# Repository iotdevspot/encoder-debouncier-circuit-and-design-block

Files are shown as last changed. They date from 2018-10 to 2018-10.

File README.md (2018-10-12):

# encoder-debouncier-circuit-and-design-block

I've tried to use an encoder in one of my previous projects and it was quite hard to use due to the bouncing. Here is two version of encoder debouncer circuits (as an Eagle Design Blocks .dbl) with links where I found them and I've created some modules to test them (.brd, and .sch files). The second version had been implemented and it worked fine for me. I've managed to create a quite cool UI with it. Every component has 3D model, so I've synced it with Fusion360 too. Here is how it's look: 

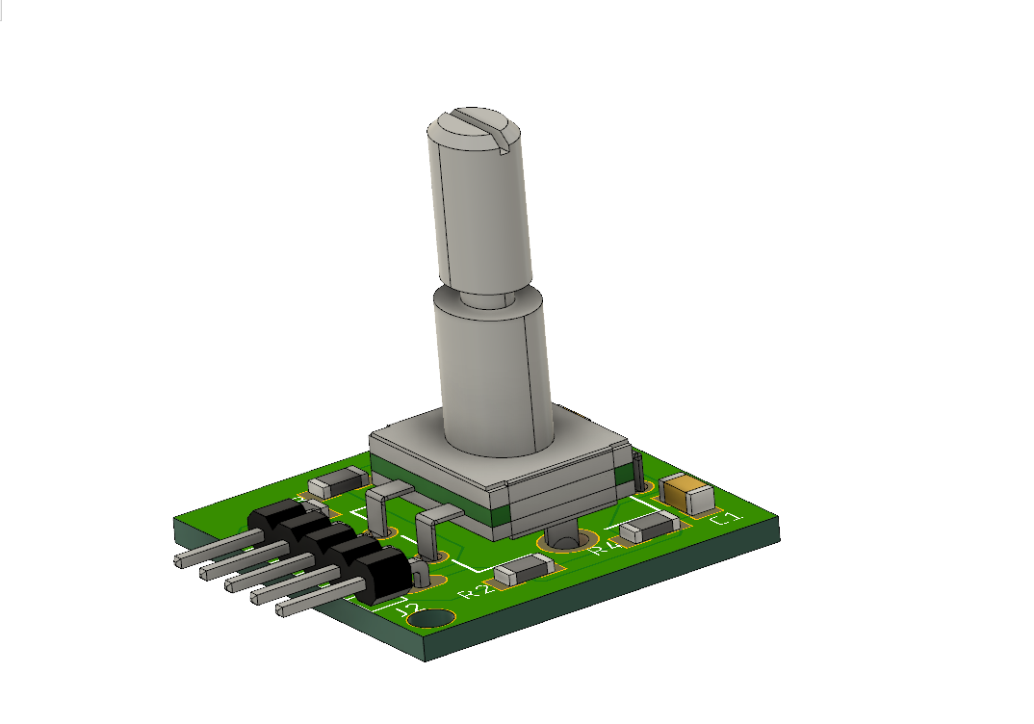
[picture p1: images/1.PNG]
image of Fusion360


*[ROBERT DEE](https://grabcad.com/library/rotary-encoder-6)s encoder model had been used from GrabCAD*

**How to connect (module to board):**
- 5V - supply voltage
- GND - ground
- SW - button input, digital in
- DT - B channel of encoder
- CLK - A channel of encoder

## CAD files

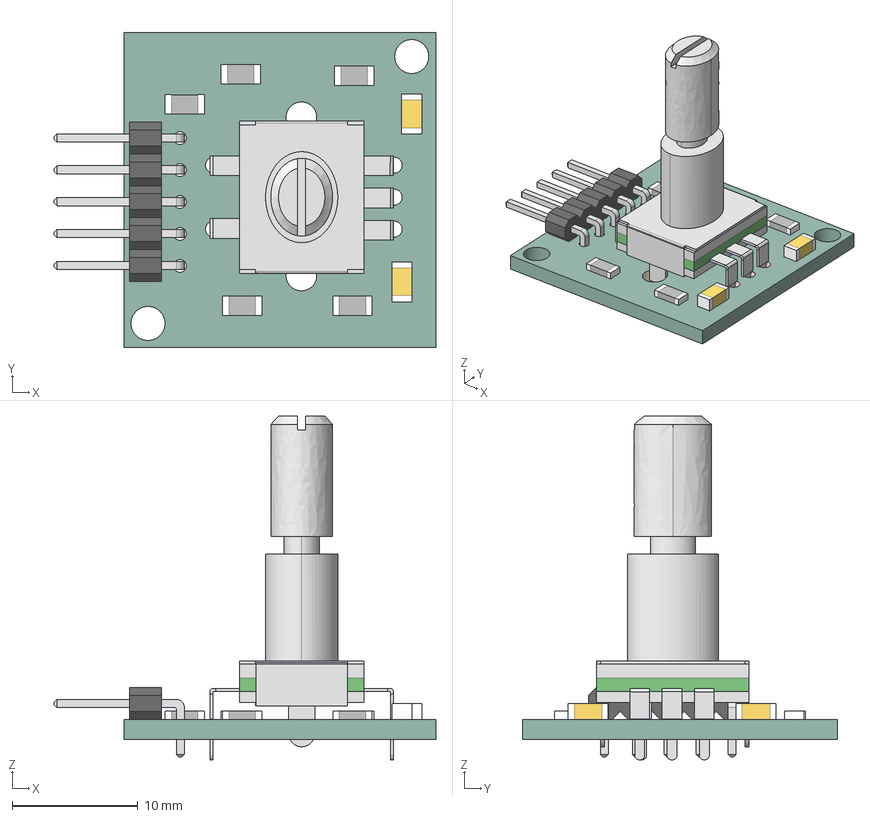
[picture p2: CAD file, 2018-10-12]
type1/smd/encoder-switch-type1-smd v3.step
30.4 x 25.0 x 27.3 mm
Board
10nF x 2
1X05/90
82K x 5

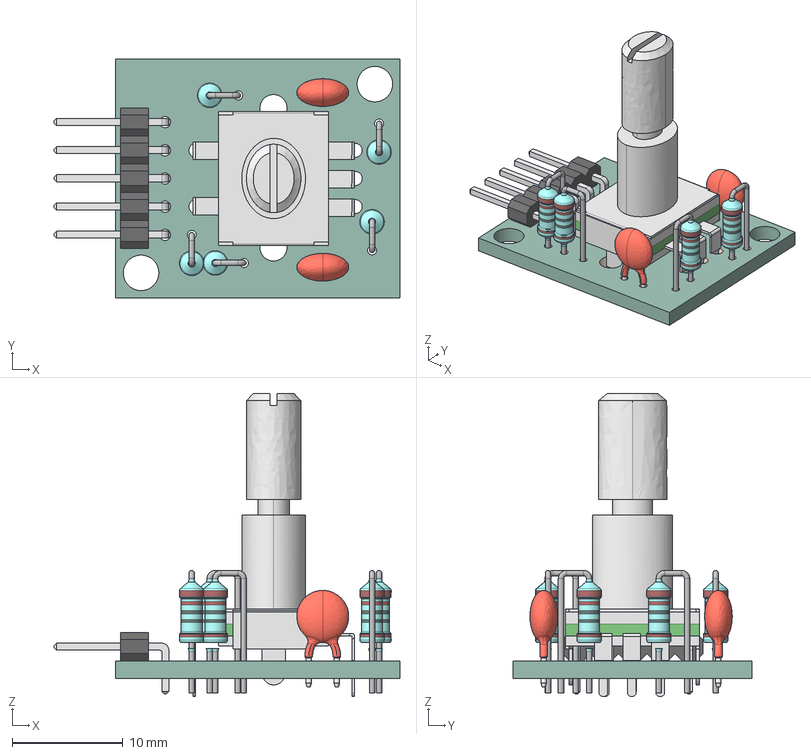
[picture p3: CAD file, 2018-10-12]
type1/tht/encoder-switch-type1-tht v2.step
31.2 x 21.6 x 27.3 mm
Board
82K x 5
10nF x 2
1X05/90

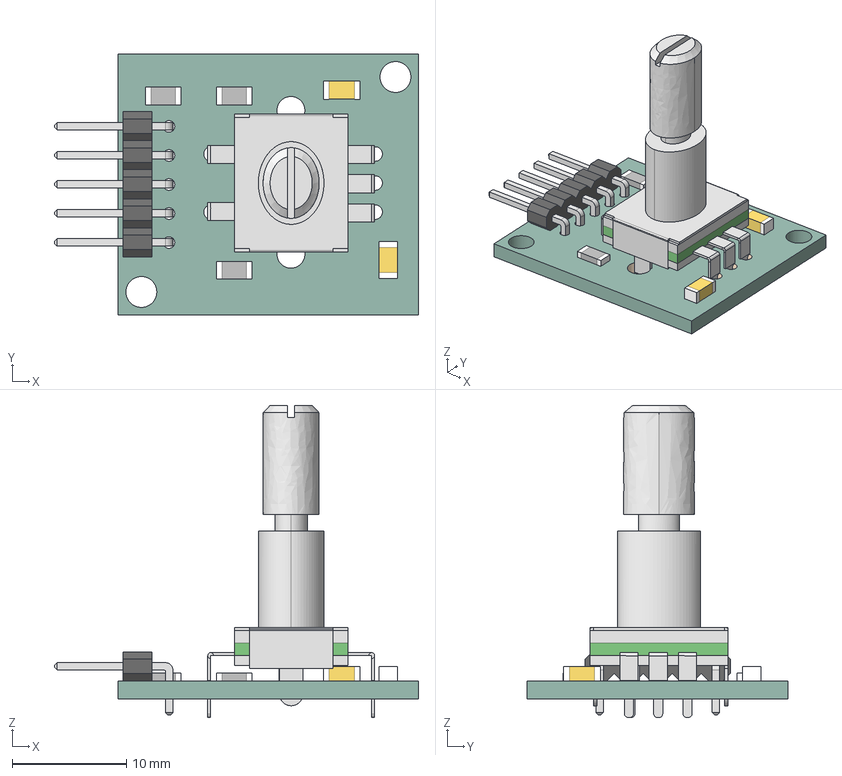
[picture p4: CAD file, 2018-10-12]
type2/smd/encoder-switch-type2-smd v2.step
31.8 x 22.9 x 27.3 mm
Board
100nF x 2
1X05/90
27K x 3

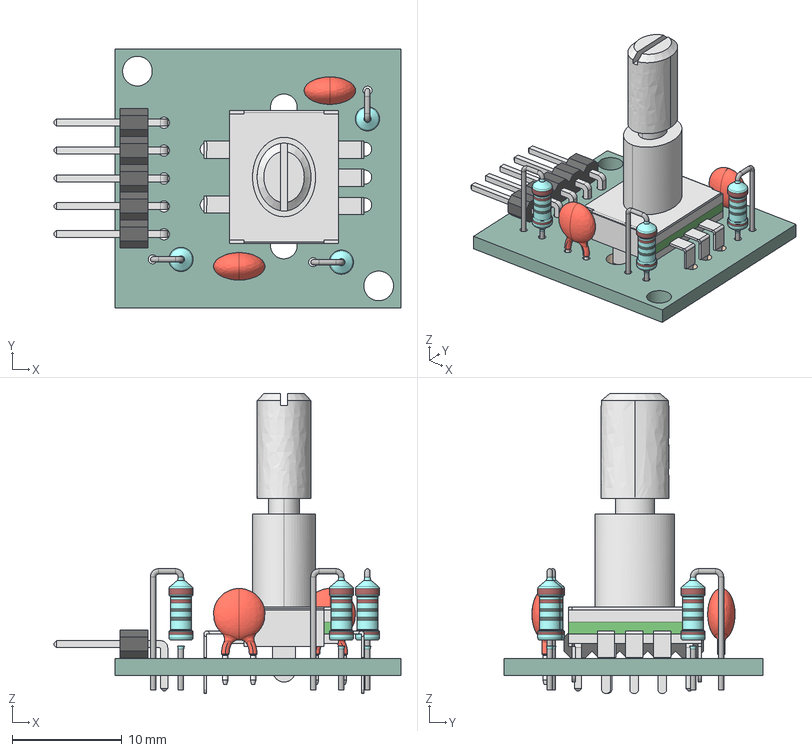
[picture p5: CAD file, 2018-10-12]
type2/tht/encoder-switch-type2-tht v1.step
31.6 x 23.6 x 27.3 mm
Board
100nF x 2
1X05/90
27K x 3

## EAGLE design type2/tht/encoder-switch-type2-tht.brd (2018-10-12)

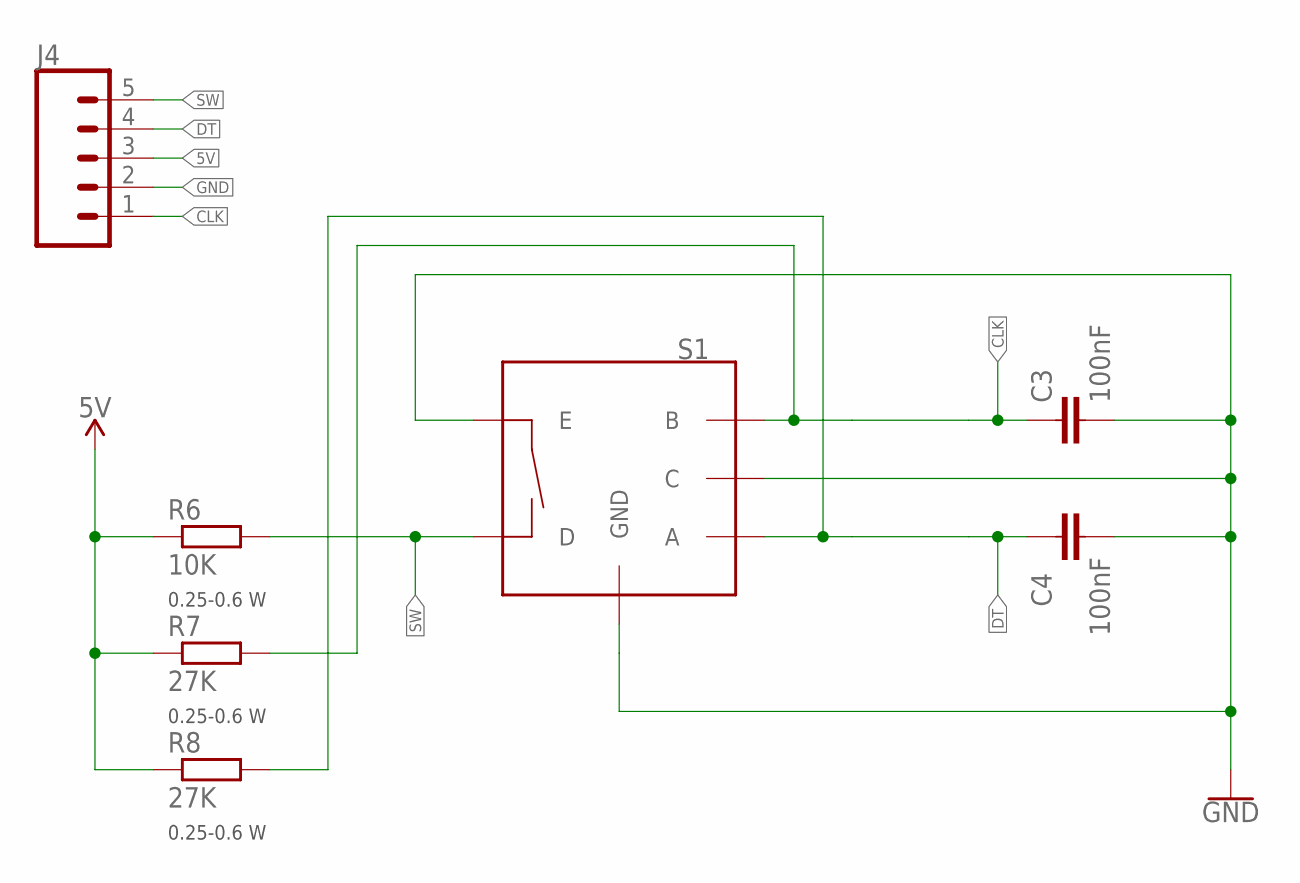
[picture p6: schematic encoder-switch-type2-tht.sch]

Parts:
C3, C4: 100nF; C025-024X044
J4: CONN_051X05LA; 1X05/90
R6: 10K; 0204V
R7, R8: 27K; 0204V
S1: ENCODER_SWITCH; ROTARY_ENC_PLAIN

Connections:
5V: J4.3, R6.1, R7.1, R8.1
CLK: C3.1, J4.1, R7.2, S1.B
DT: C4.1, J4.4, R8.2, S1.A
GND: C3.2, C4.2, J4.2, S1.C, S1.E, S1.GND1 (GND), S1.GND2 (GND)
SW: J4.5, R6.2, S1.D

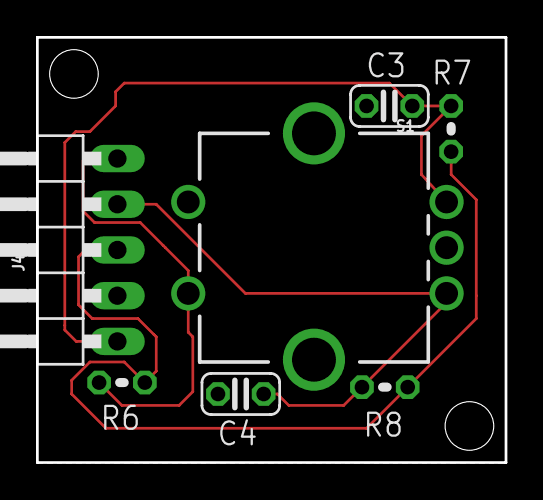
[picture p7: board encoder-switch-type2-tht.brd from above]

Board: 2 copper layers, 26.0 x 23.6 mm, 7 parts (0 on the bottom side), 5 nets.

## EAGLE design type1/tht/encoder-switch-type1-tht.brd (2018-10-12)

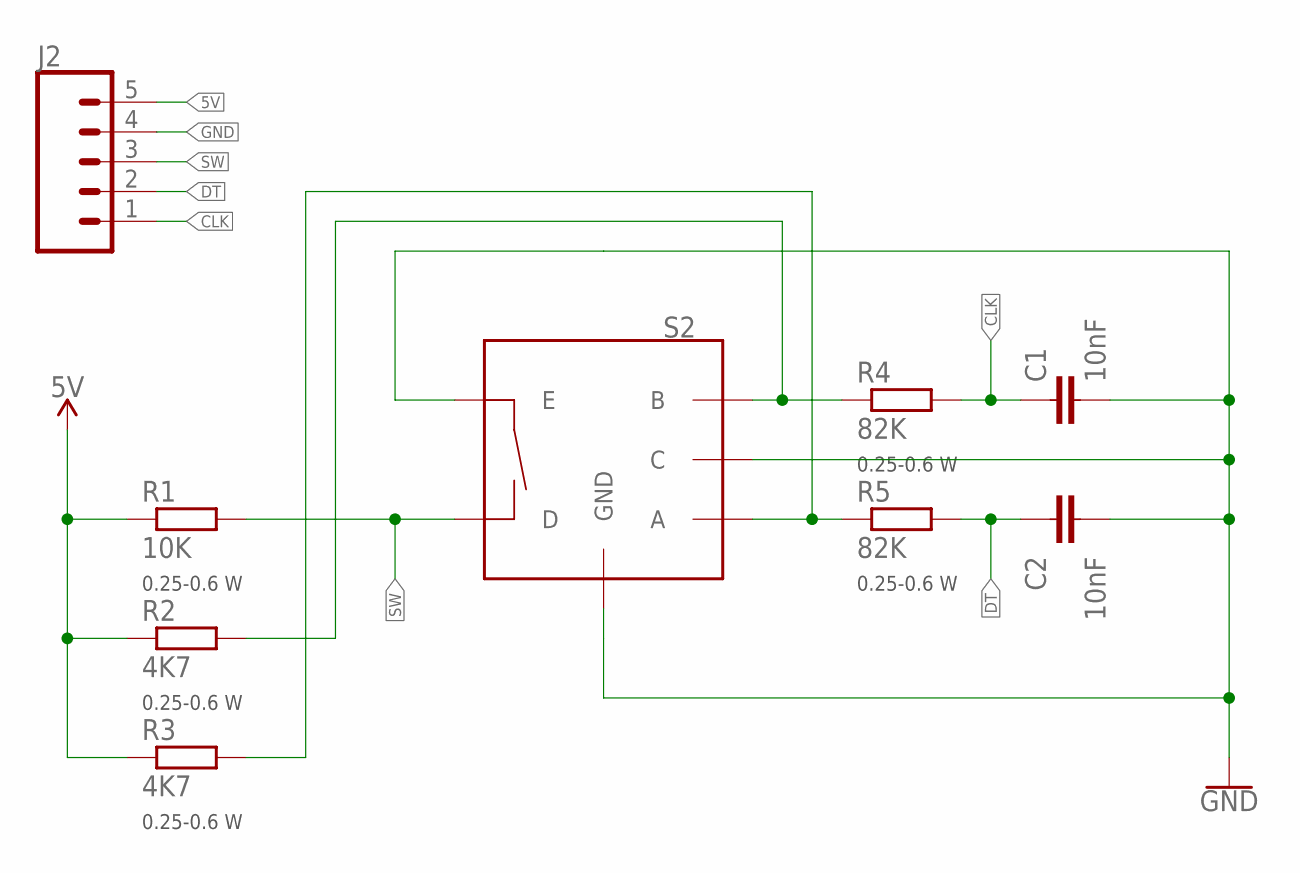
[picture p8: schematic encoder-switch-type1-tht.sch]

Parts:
C1, C2: 10nF; C025-024X044
J2: CONN_051X05LA; 1X05/90
R1: 10K; 0204V
R2, R3: 4K7; 0204V
R4, R5: 82K; 0204V
S2: ENCODER_SWITCH; ROTARY_ENC_PLAIN

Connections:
5V: J2.5, R1.1, R2.1, R3.1
CLK: C1.1, J2.1, R4.2
DT: C2.1, J2.2, R5.2
GND: C1.2, C2.2, J2.4, S2.C, S2.E, S2.GND1 (GND), S2.GND2 (GND)
unnamed: R2.2, R4.1, S2.B
unnamed: R3.2, R5.1, S2.A
SW: J2.3, R1.2, S2.D

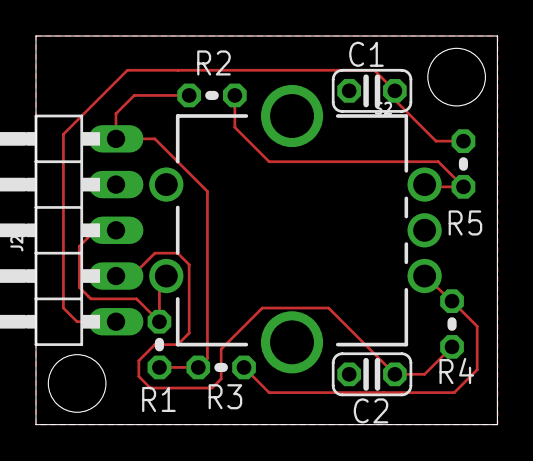
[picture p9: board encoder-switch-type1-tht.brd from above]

Board: 2 copper layers, 25.6 x 21.6 mm, 9 parts (0 on the bottom side), 7 nets.

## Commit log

2018-10-05 Design blocks, encoder debouncer modules added
    [encoder-switch-type1-smd.brd, encoder-switch-type1-smd.sch, encoder-switch-type1-tht.brd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]
2018-10-12 STEP files added, modified modules updated
    [encoder-switch-type1-smd v3.step, encoder-switch-type1-tht v2.step, encoder-switch-type1-tht.brd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]

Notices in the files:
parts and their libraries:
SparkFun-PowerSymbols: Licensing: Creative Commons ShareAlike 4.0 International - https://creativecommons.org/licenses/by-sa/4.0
